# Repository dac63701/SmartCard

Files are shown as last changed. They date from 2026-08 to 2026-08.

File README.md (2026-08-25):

# Smart Card
A nRF54L15 based Bluetooth Tracker in a Credit Card sized package

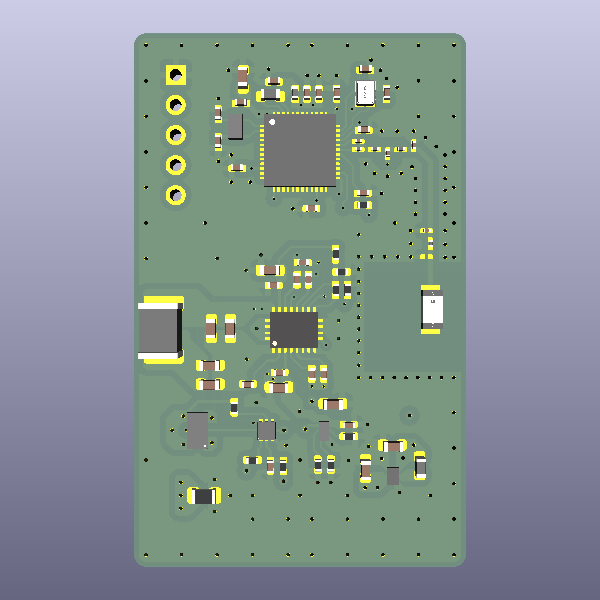
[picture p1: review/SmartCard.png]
Smart Card PCBA


The goal of this project was to create a small and slim Bluetooth tracker that would fit into a credit card enclosure. To do this, a 0.8mm thin 80mah battery was used along with a 0.8mm PCB. The device makes use of wireless charging with a BQ51013B so that it is easy to use and keep charged. There is also a custom battery charger and protection circuit. It uses a BQ298009 for protection and a BQ25100 for charging. Finally there is a TPS62840 for sourcing 1v8 from the battery and the antenna along with a matching network.

## Components
Check the [bom](https://github.com/dac63701/SmartCard/blob/main/production/bom.csv) for more details on the PCB components.
Standard PLA was used for the Prototype case.
The battery is a 084545 battery from [Alibaba](https://www.alibaba.com/product-detail/GEB-ultra-0-8mm-Thickness-084545_1601492203632.html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).

## Case Files
Check [OnShape](https://cad.onshape.com/documents/73dd8871ae024b497bb44b73/w/69cf76015be0ecbff129bf07/e/5547e5b9bb5f69b8ddd4b47d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) for the files.

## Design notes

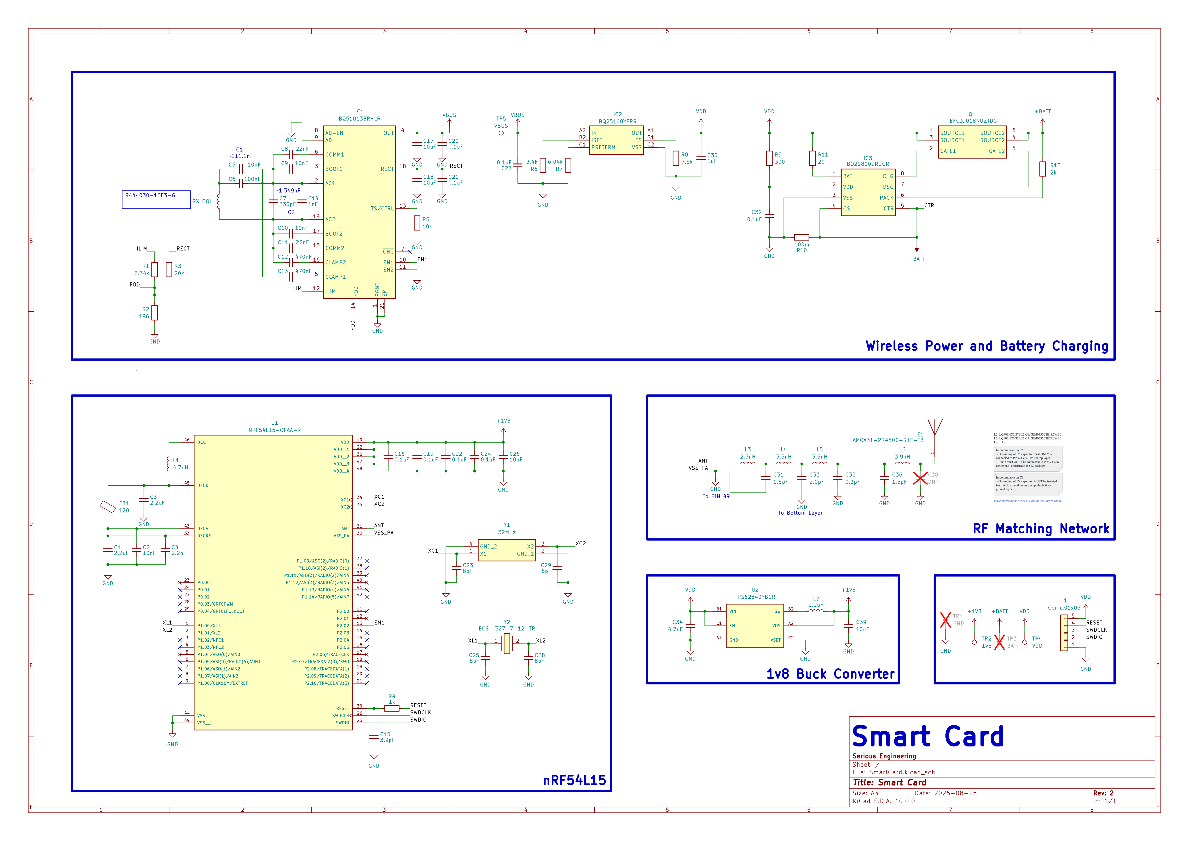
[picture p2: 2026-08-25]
review/SmartCard_Schematic.png

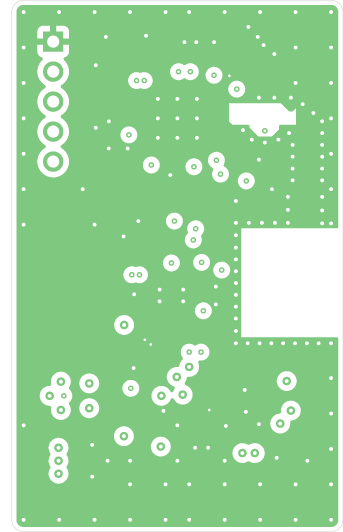
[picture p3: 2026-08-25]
review/SmartCard-In1_Cu.png

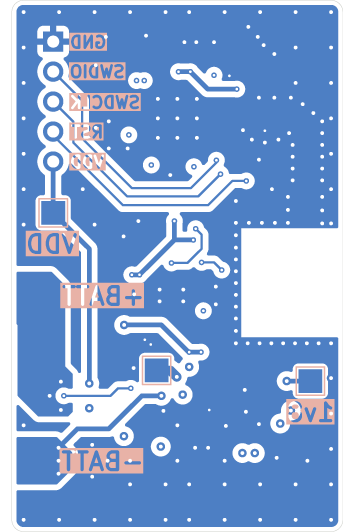
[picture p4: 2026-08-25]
review/SmartCard-B_Cu.png

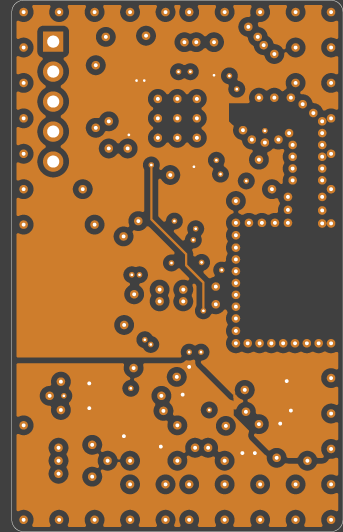
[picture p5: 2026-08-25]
review/SmartCard-In2_Cu.png

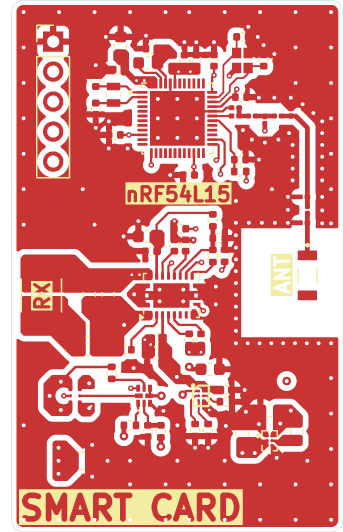
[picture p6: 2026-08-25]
review/SmartCard-F_Cu.png

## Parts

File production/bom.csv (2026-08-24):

Designator | Footprint | Quantity | Value | LCSC Part #
C1, C3 | 0402 | 2 | 2.2uF | GRM155D80J225ME95D
C10, C2, C9 | 0402 | 3 | 10nF | GRM155R71H103KA88D
C11, C8 | 0402 | 2 | 22nF | GRM155R71H223KA12D
C12, C13 | 0402 | 2 | 470nF | C1005X5R1E474K050BB
C14 | 0603 | 1 | 1nF | GRM155R71H102KA01D
C15 | 0402 | 1 | 3.9pF | GRM1555C1H3R9BA01D
C16, C19, C20, C21, C22, C24, C27, C32 | 0402 | 8 | 0.1uF | GRM155R71H104KE14D
C17, C18, C26, C39 | 0603 | 4 | 10uF | GRT188R61E106ME13D
C23, C25, C28, C29 | 0402 | 4 | 8pF | GJM1555C1H8R0BB01D
C30 | 0603 | 1 | 1uF | EMK105BJ105KV-F
C31, C36 | 0201 | 2 | 1.5pF | GJM0335C1E1R5WB01D
C33 | 0201 | 1 | 2.0pF | GRM0335C1H2R0WA01D
C34 | 0603 | 1 | 4.7uF | GMC10X5R475K10NT
C35 | 0201 | 1 | 0.3pF | GRM0335C1ER30WA01D
C4 | 0402 | 1 | 2.2nF | GRM155R71C223KA01D
C5 | 0603 | 1 | 10nF | GRM155R71H103KA88D
C6 | 0603 | 1 | 100nF | GRM155R71H104KE14D
C7 | 0603 | 1 | 330pF | GRM155R71H331KA01D
E1 | XDCR_AMCA31-2R450G-S1F-T3 | 1 | AMCA31-2R450G-S1F-T3 | AMCA31-2R450G-S1F-T3
FB1 | 0402 | 1 | 120 | 2504021217Y0
IC1 | Texas_VQFN-RHL-20 | 1 | BQ51013BRHLR | BQ51013BRHLR
IC2 | BGA6C40P2X3_88X158X50 | 1 | BQ25100YFPR | BQ25100YFPR
IC3 | BQ298009RUGR | 1 | BQ298009RUGR | BQ298009RUGR
L1 | 0603 | 1 | 4.7uH | MLZ1608CWC4R7MTD25
L2 | 1812 | 1 | RX COIL | WR444030-16F3-G
L3 | 0201 | 1 | 2.7nH | LQP03HQ2N7B02D
L4, L5 | 0201 | 2 | 3.5nH | LQP03HQ3N5B02D
L6 | 0201 | 1 | 3.9nH | LQP03TQ3N9B02D
L7 | 0603 | 1 | 2.2uH | LQM18PN2R2MGHD
Q1 | EFC3J018NUZTDG | 1 | EFC3J018NUZTDG | EFC3J018NUZTDG
R1 | 0402 | 1 | 6.34k | RC0402FR-076K34L
R10 | 0805 | 1 | 100m | RL1220S-R10-F
R11 | 0402 | 1 | 20 | RC0402FR-0720RL
R13 | 0402 | 1 | 2k | RC0402FR-0720KL
R2 | 0402 | 1 | 196 | CRCW0402196RFKED
R3 | 0402 | 1 | 20k | RC0402FR-0720KL
R4 | 0402 | 1 | 1k | RC0402FR-071KL
R5 | 0402 | 1 | 10k | RC0402FR-0710KL
R6 | 0402 | 1 | 3.4k | RC0402FR-073K4L
R7 | 0402 | 1 | 6.04k | RC0402FR-076K04L
R8 | 0402 | 1 | 7.5k | RC0402FR-077K5L
R9 | 0402 | 1 | 300 | RC0402FR-07300RL
U1 | QFN40P600X600X90-49N | 1 | NRF54L15-QFAA-R | NRF54L15-QFAA-R
U2 | TPS62840YBGR | 1 | TPS62840YBGR | TPS62840YBGR
Y1 | ABM11W300000MHZ4B1UT3 | 1 | 32MHz | ABM11W-32.0000MHZ-7-D1X-T3
Y2 | ECS327712TR | 1 | ECS-.327-7-12-TR | ECS-.327-7-12-TR

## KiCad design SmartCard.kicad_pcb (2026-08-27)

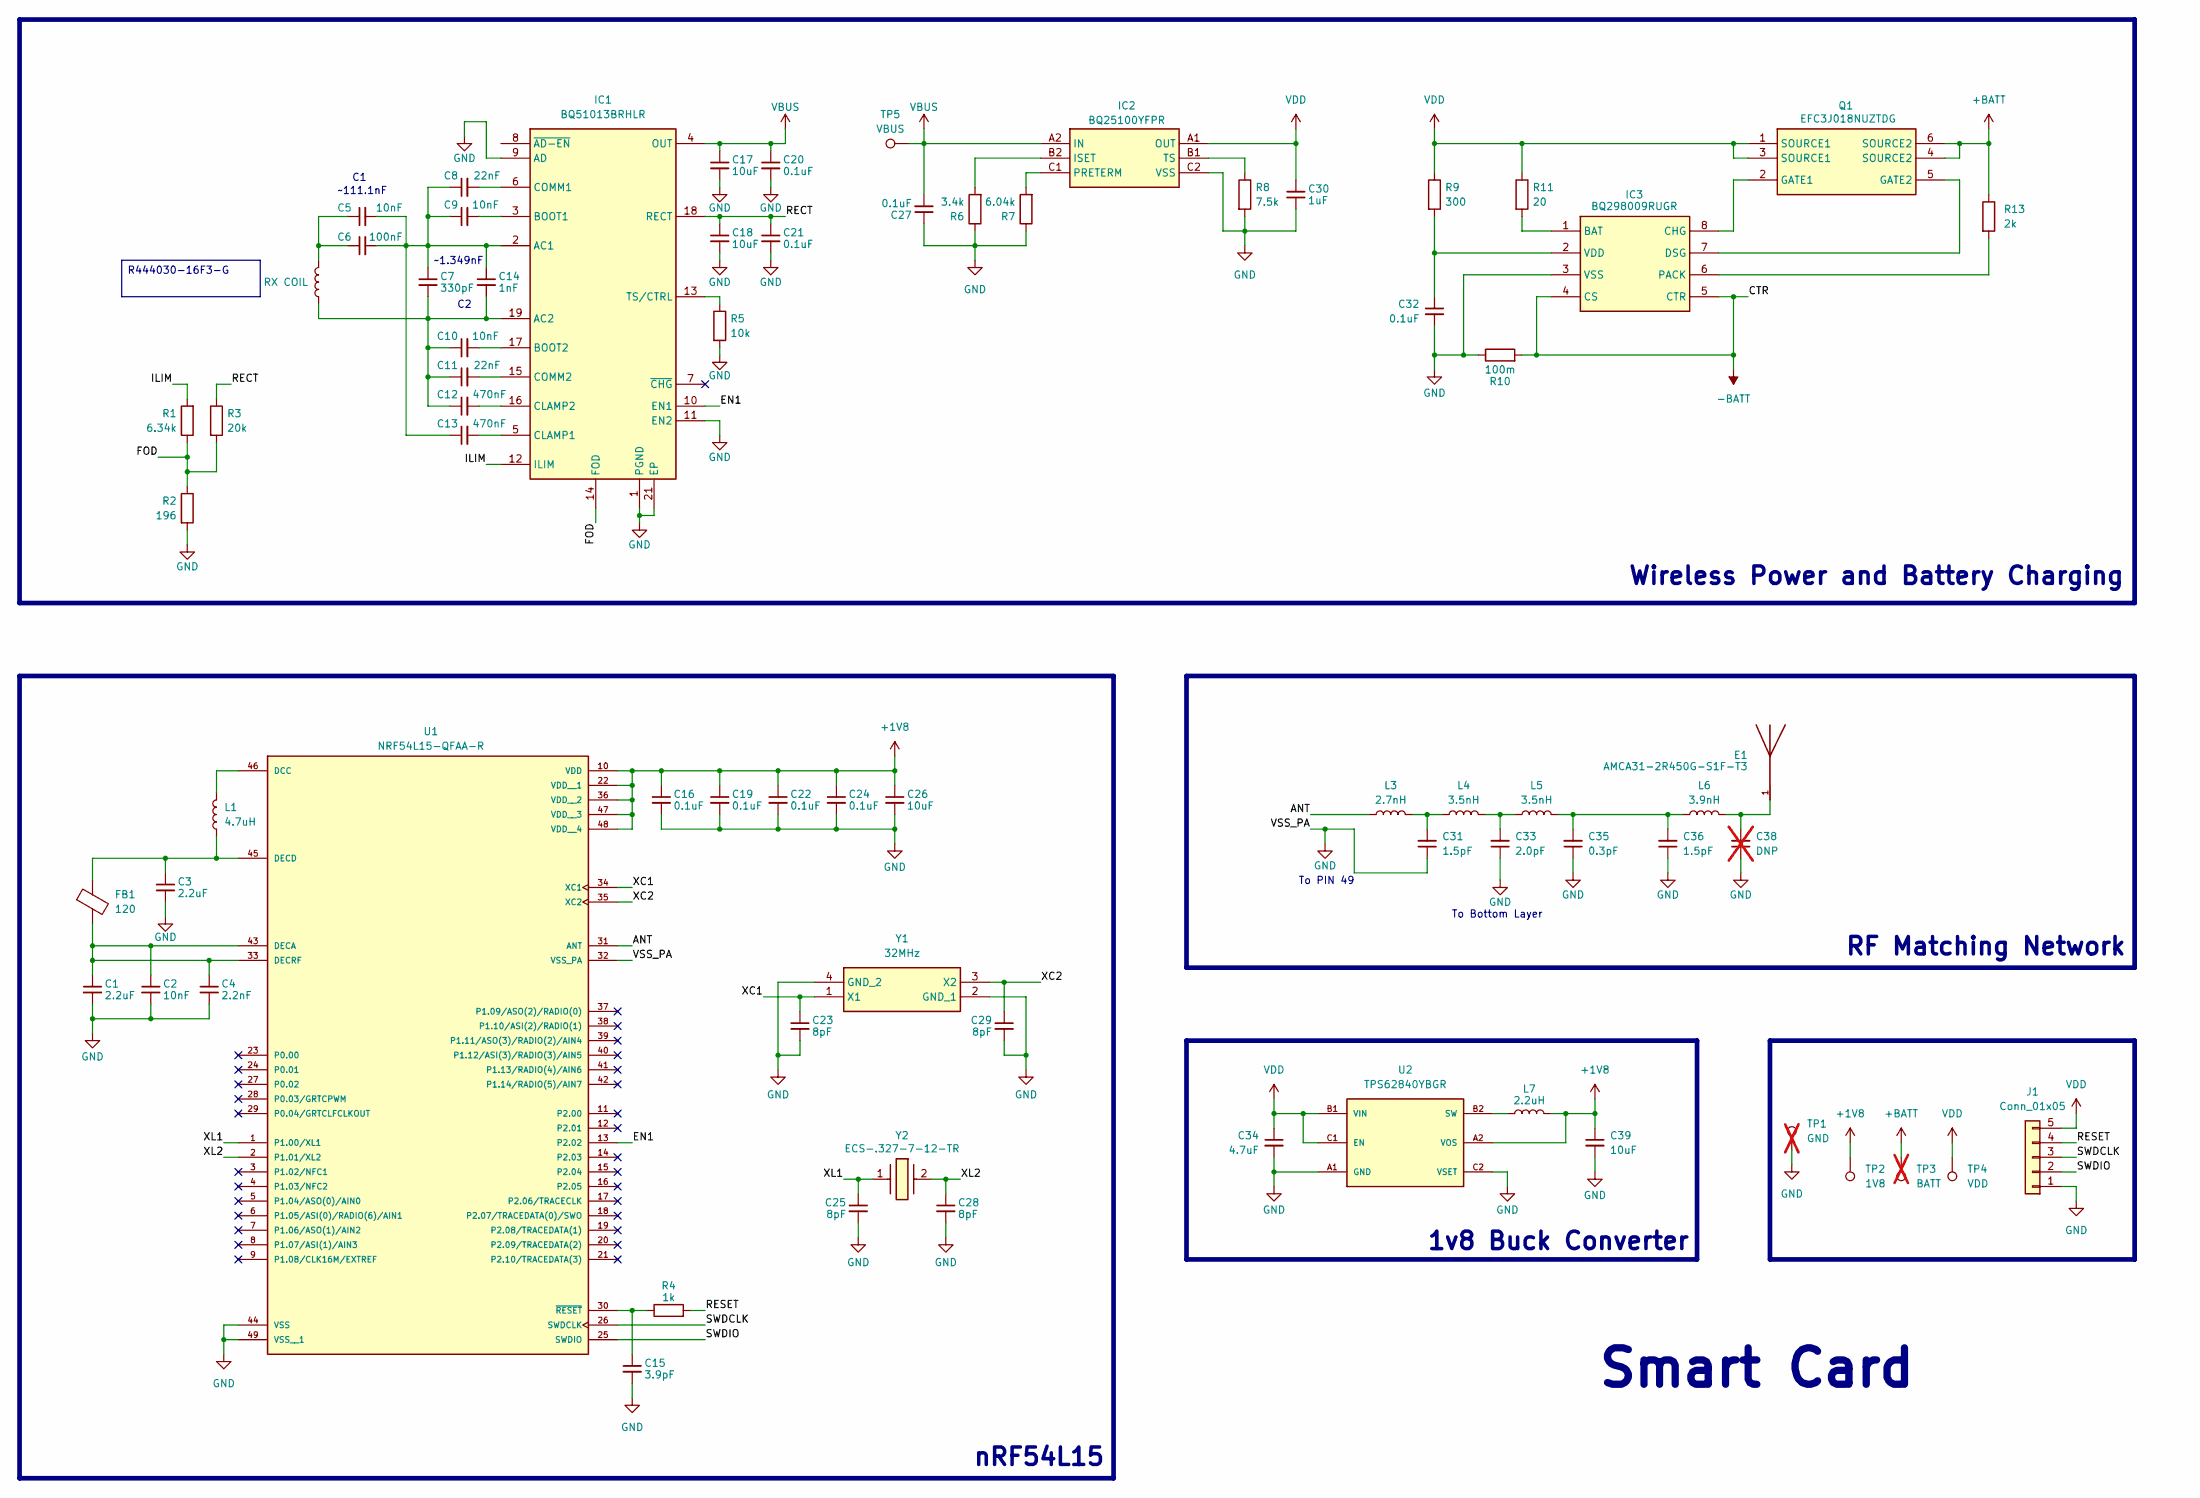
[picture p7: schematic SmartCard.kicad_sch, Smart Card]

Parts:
C1, C3: 2.2uF; C_0402_1005Metric; MPN GRM155D80J225ME95D
C2, C9, C10: 10nF; C_0402_1005Metric; MPN GRM155R71H103KA88D
C4: 2.2nF; C_0402_1005Metric; MPN GRM155R71C223KA01D
C5: 10nF; C_0603_1608Metric; MPN GRM155R71H103KA88D
C6: 100nF; C_0603_1608Metric; MPN GRM155R71H104KE14D
C7: 330pF; C_0603_1608Metric; MPN GRM155R71H331KA01D
C8, C11: 22nF; C_0402_1005Metric; MPN GRM155R71H223KA12D
C12, C13: 470nF; C_0402_1005Metric; MPN C1005X5R1E474K050BB
C14: 1nF; C_0603_1608Metric; MPN GRM155R71H102KA01D
C15: 3.9pF; C_0402_1005Metric; MPN GRM1555C1H3R9BA01D
C16, C19, C20, C21, C22, C24, C27, C32: 0.1uF; C_0402_1005Metric; MPN GRM155R71H104KE14D
C17, C18, C26, C39: 10uF; C_0603_1608Metric; MPN GRT188R61E106ME13D
C23, C25, C28, C29: 8pF; C_0402_1005Metric; MPN GJM1555C1H8R0BB01D
C30: 1uF; C_0603_1608Metric; MPN EMK105BJ105KV-F
C31, C36: 1.5pF; C_0201_0603Metric; MPN GJM0335C1E1R5WB01D
C33: 2.0pF; C_0201_0603Metric; MPN GRM0335C1H2R0WA01D
C34: 4.7uF; C_0603_1608Metric; MPN GMC10X5R475K10NT
C35: 0.3pF; C_0201_0603Metric; MPN GRM0335C1ER30WA01D
C38: DNP; C_0201_0603Metric; MPN DNP; not fitted
E1: AMCA31-2R450G-S1F-T3; XDCR_AMCA31-2R450G-S1F-T3; PARTREV 03-21-19
FB1: 120; L_0402_1005Metric; MPN 2504021217Y0
IC1: BQ51013BRHLR; Texas_VQFN-RHL-20; Mouser Part Number 595-BQ51013BRHLR
IC2: BQ25100YFPR; BGA6C40P2X3_88X158X50; Mouser Part Number 595-BQ25100YFPR
IC3: BQ298009RUGR; Mouser Part Number 595-BQ298009RUGR
J1: Conn_01x05; PinHeader_1x05_P2.54mm_Vertical
L1: 4.7uH; L_0603_1608Metric; MPN MLZ1608CWC4R7MTD25
L2: RX COIL; L_1812_4532Metric_Pad1.30x3.40mm_HandSolder; MPN WR444030-16F3-G
L3: 2.7nH; L_0201_0603Metric; MPN LQP03HQ2N7B02D
L4, L5: 3.5nH; L_0201_0603Metric; MPN LQP03HQ3N5B02D
L6: 3.9nH; L_0201_0603Metric; MPN LQP03TQ3N9B02D
L7: 2.2uH; L_0603_1608Metric; MPN LQM18PN2R2MGHD
Q1: EFC3J018NUZTDG; Mouser Part Number 863-EFC3J018NUZTDG
R1: 6.34k; R_0402_1005Metric; MPN RC0402FR-076K34L
R2: 196; R_0402_1005Metric; MPN CRCW0402196RFKED
R3: 20k; R_0402_1005Metric; MPN RC0402FR-0720KL
R4: 1k; R_0402_1005Metric; MPN RC0402FR-071KL
R5: 10k; R_0402_1005Metric; MPN RC0402FR-0710KL
R6: 3.4k; R_0402_1005Metric; MPN RC0402FR-073K4L
R7: 6.04k; R_0402_1005Metric; MPN RC0402FR-076K04L
R8: 7.5k; R_0402_1005Metric; MPN RC0402FR-077K5L
R9: 300; R_0402_1005Metric; MPN RC0402FR-07300RL
R10: 100m; R_0805_2012Metric; MPN RL1220S-R10-F
R11: 20; R_0402_1005Metric; MPN RC0402FR-0720RL
R13: 2k; R_0402_1005Metric; MPN RC0402FR-0720KL
TP1: GND; TestPoint_Pad_2.0x2.0mm; not fitted
TP2: 1V8; TestPoint_Pad_2.0x2.0mm
TP3: BATT; TestPoint_Pad_2.0x2.0mm; not fitted
TP4: VDD; TestPoint_Pad_2.0x2.0mm
TP5: VBUS; TestPoint_Pad_2.0x2.0mm
U1: NRF54L15-QFAA-R; QFN40P600X600X90-49N; PARTREV 0.8
U2: TPS62840YBGR; PARTREV D
Y1: 32MHz; ABM11W300000MHZ4B1UT3; Manufacturer_Part_Number ABM11W-25.0000MHZ-7-D1X-T3
Y2: ECS-.327-7-12-TR; ECS327712TR; Mouser Part Number 520-ECS-.327-7-12-TR

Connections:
+1V8: C16.1, C19.1, C22.1, C24.1, C26.1, C39.1, L7.2, TP2.1 (1_1), U1.10 (VDD), U1.22 (VDD__1), U1.36 (VDD__2), U1.47 (VDD__3), U1.48 (VDD__4), U2.A2 (VOS)
+BATT: Q1.4 (SOURCE2), Q1.6 (SOURCE2), R13.1, TP3.1
-BATT: IC3.4 (CS), IC3.5 (CTR), R10.2
/ANT: L3.1, U1.31 (ANT)
/EN1: IC1.10 (EN1), U1.13 (P2.02)
/FOD: IC1.14 (FOD), R1.1, R2.1, R3.2
/ILIM: IC1.12 (ILIM), R1.2
/RECT: C18.1, C21.1, IC1.18 (RECT), R3.1
/RESET: J1.4, R4.2
/SWDCLK: J1.3, U1.26 (SWDCLK)
/SWDIO: J1.2, U1.25 (SWDIO)
/XC1: C23.1, U1.34 (XC1), Y1.1 (X1)
/XC2: C29.1, U1.35 (XC2), Y1.3 (X2)
/XL1: C25.1, U1.1 (P1.00/XL1), Y2.1
/XL2: C28.1, U1.2 (P1.01/XL2), Y2.2 (OUT/IN_2)
GND: C1.2, C2.2, C3.2, C4.2, C15.2, C16.2, C17.2, C18.2, C19.2, C20.2, C21.2, C22.2, C23.2, C24.2, C25.2, C26.2, C27.1, C28.2, C29.2, C30.2, C31.1, C32.2, C33.1, C34.2, C35.1, C36.1, C38.1, C39.2, IC1.1 (PGND), IC1.9 (AD), IC1.11 (EN2), IC1.20 (PGND), IC1.21 (EP), IC2.C2 (VSS), IC3.3 (VSS), J1.1, R2.2, R5.2, R6.1, R7.1, R8.2, R10.1, TP1.1, U1.32 (VSS_PA), U1.44 (VSS), U1.49 (VSS__1), U2.A1 (GND), U2.C2 (VSET), Y1.2 (GND_1), Y1.4 (GND_2)
unnamed: C5.1, C6.1, L2.2
unnamed: C31.2, L3.2, L4.1
unnamed: C33.2, L4.2, L5.1
unnamed: C35.2, C36.2, L5.2, L6.1
unnamed: C38.2, E1.1, L6.2
unnamed: C5.2, C6.2, C7.1, C8.1, C9.1, C13.1, C14.1, IC1.2 (AC1)
unnamed: C7.2, C10.1, C11.1, C12.1, C14.2, IC1.19 (AC2), L2.1
unnamed: C9.2, IC1.3 (BOOT1)
unnamed: C10.2, IC1.17 (BOOT2)
unnamed: C13.2, IC1.5 (CLAMP1)
unnamed: C12.2, IC1.16 (CLAMP2)
unnamed: C8.2, IC1.6 (COMM1)
unnamed: C11.2, IC1.15 (COMM2)
unnamed: IC1.13 (TS/CTRL), R5.1
unnamed: IC2.B2 (ISET), R6.2
unnamed: IC2.C1 (PRETERM), R7.2
unnamed: IC2.B1 (TS), R8.1
unnamed: IC3.1 (BAT), R11.2
unnamed: IC3.8 (CHG), Q1.2 (GATE1)
unnamed: IC3.7 (DSG), Q1.5 (GATE2)
unnamed: IC3.6 (PACK), R13.2
unnamed: C32.1, IC3.2 (VDD), R9.2
unnamed: L1.2, U1.46 (DCC)
unnamed: C1.1, C2.1, C4.1, FB1.2, U1.33 (DECRF), U1.43 (DECA)
unnamed: C3.1, FB1.1, L1.1, U1.45 (DECD)
unnamed: C15.1, R4.1, U1.30 (~RESET)
unnamed: L7.1, U2.B2 (SW)
VBUS: C17.1, C20.1, C27.2, IC1.4 (OUT), IC2.A2 (IN), TP5.1 (1_1)
VDD: C30.1, C34.1, IC2.A1 (OUT), J1.5, Q1.1 (SOURCE1), Q1.3 (SOURCE1), R9.1, R11.1, TP4.1 (1_1), U2.B1 (VIN), U2.C1 (EN)

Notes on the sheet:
~1.349nF
nRF54L15
1v8 Buck Converter
~111.1nF
Wireless Power and Battery Charging
RF Matching Network
To PIN 49
To Bottom Layer
Smart Card
R444030-16F3-G

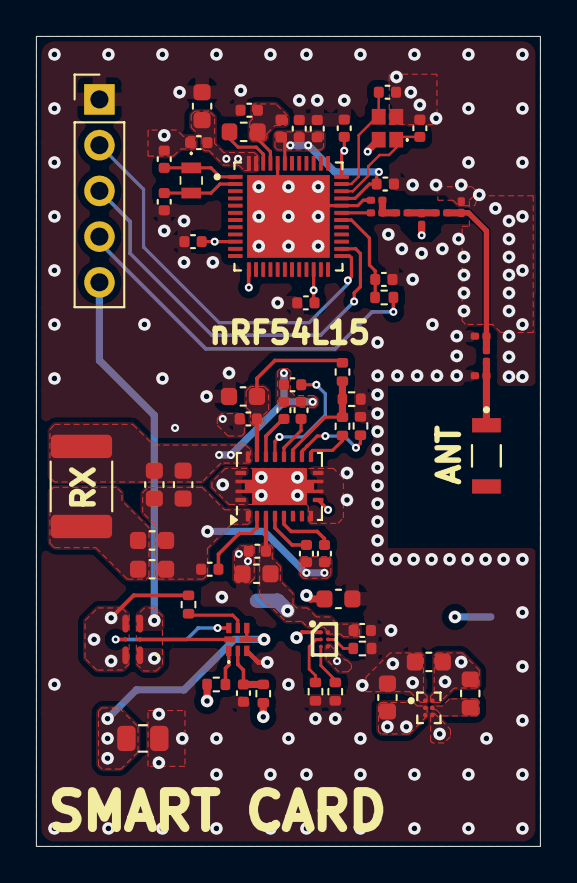
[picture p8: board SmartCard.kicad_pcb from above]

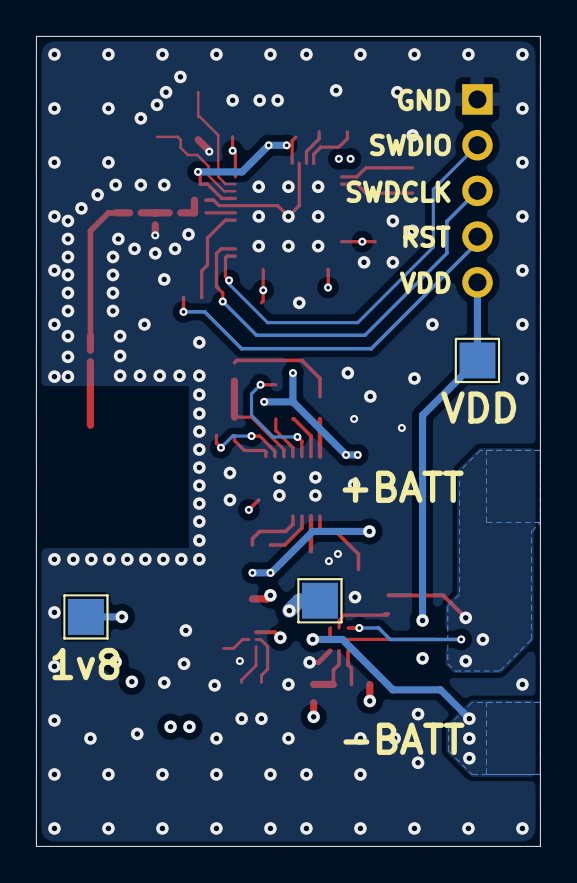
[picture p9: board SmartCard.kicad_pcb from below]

Board: 4 copper layers, 28.0 x 45.0 mm, 71 parts (3 on the bottom side), 45 nets.

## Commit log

2026-05-07 Refactor KiCad schematic symbols & positions
    Adjust schematic symbols and component placements in SmartCard.kicad_sch and update project metadata in SmartCard.kicad_pro. Changes include repositioning pins and boxes for multiple components (e.g.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
    [SmartCard.kicad_sch]
2026-05-11 Update KiCad schematic symbols & add backups
    Add three SmartCard backup zip files and update the KiCad project files. SmartCard.kicad_sch: introduce new/updated library symbols (Abracon AMCA31 transducer, ABM11W oscillator replacing a prior part, ECS 32.768kHz crystal), adjust properties (reference, value, footprint, datasheet, manufacturer, pin names), add VDD power symbol, and relocate/update many symbol positions and junctions. SmartCard.kicad_pro: simplify used_designators entry to "C44-46,Y2,E1". These changes ensure correct component metadata and footprints in the schematic.
    [SmartCard.kicad_sch]
2026-06-05 Update KiCad prefs, board rules, schematic
    Add backup zips and update KiCad project files: expand net inspector column settings in SmartCard.kicad_prl; add comprehensive design_settings (DRC/rules, teardrops, track/tuning defaults, via/zones) and clear used_designators in SmartCard.kicad_pro; apply many edits to SmartCard.kicad_sch (add BQ25100 symbol, adjust text/footprint labels, add text_box, reposition junctions/wires, add/remove junctions and wire segments, update UUIDs). These changes capture project preferences, board DRC defaults, and schematic layout/connection fixes.
    [SmartCard.kicad_sch]
2026-07-07 finished v0.1 shematic
    [SmartCard.kicad_sch]
2026-07-24 Populate SmartCard PCB and add test points
    Adds the full KiCad PCB implementation from the previously minimal board file, including footprints, board outline, and RF/power sections. Updates the schematic with test point symbols/instances (TP1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
    [SmartCard.kicad_pcb, SmartCard.kicad_sch]
2026-08-24 mostly done just a little more work
    [SmartCard.kicad_pcb, SmartCard.kicad_sch]
2026-08-24 Added stitching vias
    [SmartCard.kicad_pcb, bom.csv, designators.csv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]
2026-08-25 mostly finished
    [SmartCard.kicad_pcb, SmartCard.kicad_sch]
2026-08-27 Smart Card r2 done
    [SmartCard.kicad_pcb]
2026-10-16 fixed schematic for v2 fixing bat management
    still need to do layout
